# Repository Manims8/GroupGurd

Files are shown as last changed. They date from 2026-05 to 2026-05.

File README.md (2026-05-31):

# GroupGuard

GroupGuard is a wearable ESP32 safety and proximity system for groups moving through crowded places such as temples, festivals, tourist spots, campuses, and markets. The project helps prevent members, especially children and elderly people, from getting separated by giving real-time distance, direction, vibration alerts, LED alerts, and SOS signaling without requiring internet or a phone app.

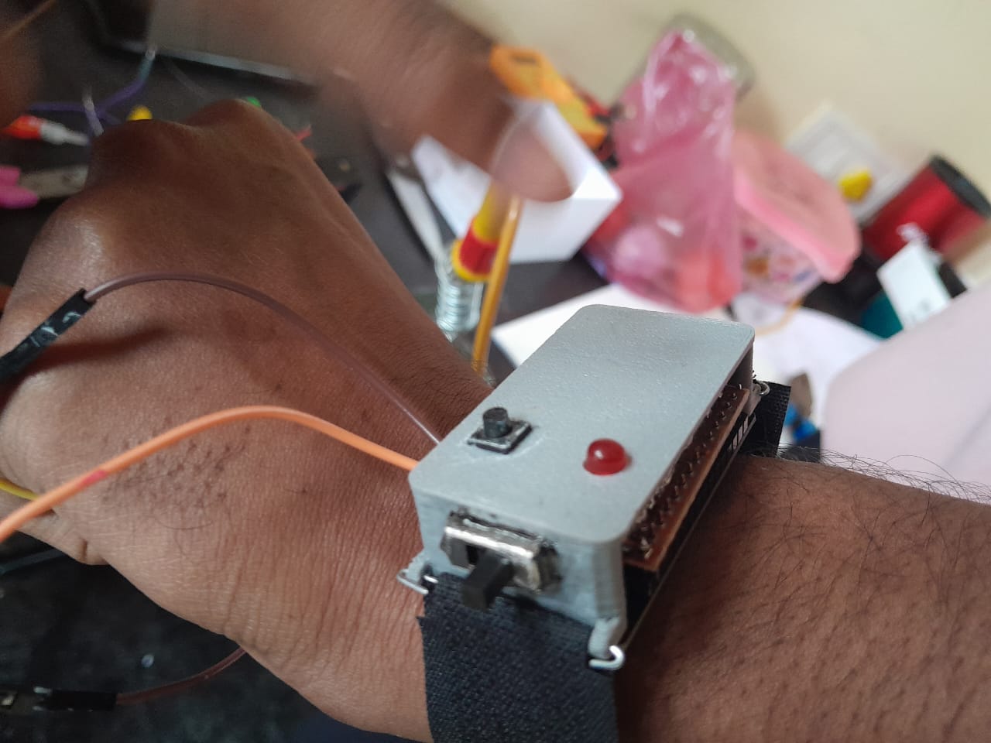
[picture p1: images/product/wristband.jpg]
GroupGuard wristband


## Problem

Crowded public spaces make it easy for group members to drift apart. Existing solutions such as CCTV, public announcements, or police assistance usually help only after someone is already missing. GroupGuard is designed as a proactive system: it alerts the group before separation becomes serious.

## Features

- Local WiFi network created by the master band, no router or internet required
- RSSI-based proximity estimation for group members
- QMC5883L compass-based directional guidance
- OLED direction and distance display on leader/display bands
- Vibration and LED alert patterns for warnings and SOS events
- Dedicated SOS button on each band
- 3D-printable enclosure models for display and non-display bands

## Demo Media

- Product photos: [`images/product/`](images/product/)
- Prototype photo: [`images/prototype/`](images/prototype/)
- Circuit diagram: [`images/circuit-diagrams/circuit diagram.png`](images/circuit-diagrams/circuit%20diagram.png)
- Demo videos: [`videos/`](videos/)
- 3D models: [`3D-designs/`](3D-designs/)

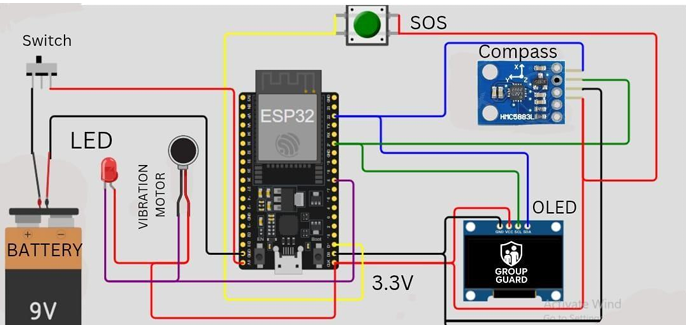
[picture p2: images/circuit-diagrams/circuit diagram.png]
Circuit diagram


## Firmware Layout

| Device | Sketch | Role |
| --- | --- | --- |
| D1 | `firmware/D1_Master/D1_Master.ino` | SoftAP, TCP server, warning sender, display master |
| D2 | `firmware/D2_Peripheral/D2_Peripheral.ino` | Headless peripheral with vibration and LED alerts |
| D3 | `firmware/D3_Display/D3_Display.ino` | Display peripheral showing D1 and D4 |
| D4 | `firmware/D4_Display/D4_Display.ino` | SPI display peripheral showing D3 and self |

## Documentation

- [Architecture](docs/architecture.md)
- [Problem Statement](docs/problem-statement.md)
- [Hardware](docs/hardware.md)
- [Communication Protocol](docs/protocol.md)
- [Testing](docs/testing.md)
- [Future Scope](docs/future-scope.md)

## Architecture

```mermaid
flowchart LR
  D1[D1 Master SoftAP<br/>192.168.4.1]
  D2[D2 Peripheral]
  D3[D3 Display]
  D4[D4 Display]

  D2 -->|D2,heading,sos,rssi| D1
  D3 -->|D3,heading,sos,rssi| D1
  D4 -->|D4,heading,sos,rssi| D1
  D1 -->|WARN| D2
  D1 -->|WARN + D1_DATA| D3
  D1 -->|WARN + D3_DATA| D4
```

## WiFi

D1 starts a SoftAP:

| Setting | Value |
| --- | --- |
| SSID | `GroupGuard` |
| Password | `Groupguard@0826` |
| D1 IP | `192.168.4.1` |
| D1 server port | `12345` |
| Peripheral server port | `54321` |

D1 does not show the WiFi password on the OLED during startup.

For public or shared deployments, change the default AP credentials in each firmware sketch before flashing.

## Hardware Pins

| Device | Button | Vibration | LED | I2C | Display |
| --- | --- | --- | --- | --- | --- |
| D1 | GPIO 15, pulldown, active-high | GPIO 5 | None | SDA 21, SCL 22 | I2C SSD1306 |
| D2 | GPIO 15, pulldown, active-high | GPIO 5 | GPIO 25 | SDA 21, SCL 22 | None |
| D3 | GPIO 15, pulldown, active-high | GPIO 5 | None | SDA 21, SCL 22 | I2C SSD1306 |
| D4 | GPIO 27, pullup, active-low | GPIO 26 | GPIO 25 | SDA 21, SCL 22 | SPI SSD1306, DC 5, RST 4 |

D4 intentionally keeps its existing active-low button wiring.

## Protocol

Peripheral uplink to D1:

```text
D#,<heading>,<sos>,<rssi>
```

D1 to D3:

```text
D1_DATA,<d1Heading>,<d3Distance>,<d4Heading>,<d4Distance>,<d4Sos>,<d4Active>
```

D1 to D4:

```text
D3_DATA,<d3Heading>,<d3Distance>,<d3Sos>,<d3Active>
```

Warning packet:

```text
WARN
```

## Flashing

Open each `.ino` in Arduino IDE from its matching folder, select the ESP32 board and port, install the required libraries, then upload:

- `WiFi`
- `Wire`
- `SPI`
- `QMC5883LCompass`
- `Adafruit GFX Library`
- `Adafruit SSD1306`

Flash D1 first so the `GroupGuard` access point is available, then flash D2, D3, and D4.

## Repository Contents

```text
firmware/      Arduino sketches for all four ESP32 devices
docs/          Architecture, hardware, protocol, testing, and future scope
images/        Product, prototype, and circuit images
videos/        Project demonstration videos
3D-designs/    STL enclosure models
```

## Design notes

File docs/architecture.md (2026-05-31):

# GroupGuard Architecture

## Device Responsibilities

D1 is the SoftAP and TCP master. It receives one-line CSV packets from D2, D3, and D4, computes approximate distance from RSSI, displays peer state, and sends warnings to every peripheral. It also relays D4 state to D3 and D3 state to D4.

D2 is headless and reports heading, SOS button state, and RSSI. It uses vibration and LED alerts.

D3 displays D1 and D4 in a two-column layout. D3 receives `D1_DATA` from D1 and reports its own state back to D1.

D4 displays D3 and self in the same two-column style. D4 receives `D3_DATA` from D1 and keeps its existing GPIO 27 active-low button wiring.

## Alert Patterns

| Event | Vibration | LED | Duration |
| --- | --- | --- | --- |
| SOS sent | 200 ms on / 200 ms off | Solid on where present | 2000 ms |
| Warning received | 300 ms on / 100 ms off | 150 ms flash where present | 3000 ms |
| D1 warning send | Solid vibration | None | 2000 ms |

## Display Model

Display devices use a split-screen peer box layout:

| Device | Left | Right |
| --- | --- | --- |
| D1 page 1 | D2 | D3 |
| D1 page 2 | D4 full-width | - |
| D3 | D1 | D4 |
| D4 | D3 | D4 self |

Each peer box shows a centered device label, a 32x30 direction arrow, and distance in meters.

## Distance Estimate

D1 estimates distance from RSSI:

```cpp
pow(10, (REF_RSSI - rssi) / (10.0 * PATH_LOSS))
```

This is an approximate proximity indicator and should be tuned in the real environment.

## Data Flow

1. Peripherals connect to D1's `GroupGuard` SoftAP.
2. Peripherals periodically send `D#,heading,sos,rssi` to D1 on port `12345`.
3. D1 updates the sender state using the sender IP from the TCP client.
4. D1 replies to D3 with D1 plus D4 state.
5. D1 replies to D4 with D3 state.
6. Pressing a warning/SOS button sends state through the same channel and triggers local alerts.

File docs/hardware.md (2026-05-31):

# Hardware

## Core Components

| Component | Purpose |
| --- | --- |
| ESP32-WROOM-32 | Main microcontroller, WiFi networking, GPIO control |
| QMC5883L/HMC5883L compass | Heading and direction sensing over I2C |
| 0.96 inch OLED display | Distance, direction, warning, and SOS display |
| Vibration motor | Haptic alert feedback |
| Push button | SOS or warning trigger |
| LED | Visual alert feedback where present |
| Li-ion/LiPo battery | Portable wearable power source |
| TP4056 charging module | Battery charging module |
| Wrist strap/enclosure | Wearable housing |

## Pin Mapping

| Device | Button | Vibration | LED | I2C | Display |
| --- | --- | --- | --- | --- | --- |
| D1 Master | GPIO 15, pulldown, active-high | GPIO 5 | None | SDA 21, SCL 22 | I2C SSD1306 |
| D2 Peripheral | GPIO 15, pulldown, active-high | GPIO 5 | GPIO 25 | SDA 21, SCL 22 | None |
| D3 Display | GPIO 15, pulldown, active-high | GPIO 5 | None | SDA 21, SCL 22 | I2C SSD1306 |
| D4 Display | GPIO 27, pullup, active-low | GPIO 26 | GPIO 25 | SDA 21, SCL 22 | SPI SSD1306, DC 5, RST 4 |

D4 intentionally uses an active-low button connected to ground. Do not change this wiring in firmware unless the physical circuit is changed.

## Circuit Diagram

Circuit diagram

## 3D Models

The repository includes two STL models:

- [`with_display.stl`](../3D-designs/with_display.stl)
- [`without_display.stl`](../3D-designs/without_display.stl)

These are intended for wristband enclosures with and without OLED display cutouts.

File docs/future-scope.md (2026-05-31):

# Future Scope

## PCB And Enclosure

Move from breadboard wiring to a custom PCB and compact enclosure. This will make the wristband smaller, more durable, and easier to wear.

## Power Optimization

Improve battery life by:

- Using ESP32 light sleep or modem sleep
- Reducing send frequency when members are close
- Increasing send frequency only when distance grows
- Turning off display or reducing refresh rate when idle

## Better Positioning

RSSI is useful for approximate threshold alerts, but not precise location. Future versions could explore:

- UWB for centimeter-level ranging
- BLE Mesh for larger low-power groups
- ESP-NOW for lightweight peer-to-peer ESP32 communication
- GPS for outdoor fallback tracking

## Mobile App

A companion app could help with:

- Naming devices
- Adjusting distance thresholds
- Viewing status of all bands
- Receiving phone notifications
- Saving test/calibration logs

## Scalability

The current system uses a star topology around D1. Larger groups may need a mesh or multi-leader architecture where family heads relay data to the main group leader.

## Field Testing

More testing should be done in:

- Busy markets
- Temples during rush hours
- Festivals
- Tourist locations
- Mixed indoor/outdoor routes

This would help tune RSSI thresholds and validate the system under realistic crowd movement.

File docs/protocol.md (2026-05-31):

# Communication Protocol

GroupGuard uses a local TCP network. D1 creates the WiFi access point and runs the central server on port `12345`. Peripherals run a server on port `54321` for warning and relay packets.

## Network

| Setting | Value |
| --- | --- |
| D1 SoftAP SSID | `GroupGuard` |
| D1 SoftAP IP | `192.168.4.1` |
| D1 server port | `12345` |
| Peripheral server port | `54321` |

Change the default password before using the project outside a controlled prototype environment.

## Peripheral To D1

Each peripheral periodically sends:

```text
D#,<heading>,<sos>,<rssi>
```

Example:

```text
D3,142,0,-61
```

Fields:

| Field | Meaning |
| --- | --- |
| `D#` | Device name, such as `D2`, `D3`, or `D4` |
| `heading` | Compass heading in degrees |
| `sos` | `1` if SOS is active, otherwise `0` |
| `rssi` | WiFi RSSI reading in dBm |

## D1 To D3

D1 sends D1 state plus D4 relay data to D3:

```text
D1_DATA,<d1Heading>,<d3Distance>,<d4Heading>,<d4Distance>,<d4Sos>,<d4Active>
```

## D1 To D4

D1 sends D3 relay data to D4:

```text
D3_DATA,<d3Heading>,<d3Distance>,<d3Sos>,<d3Active>
```

## Warning Packet

Warnings use a simple command:

```text
WARN
```

When received, peripherals trigger their vibration/LED warning pattern and display devices show a warning screen.

## Distance Formula

D1 estimates distance from RSSI:

```cpp
pow(10, (REF_RSSI - rssi) / (10.0 * PATH_LOSS))
```

RSSI distance is approximate and should be treated as a threshold signal, not exact measurement.

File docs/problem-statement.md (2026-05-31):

# Problem Statement

Group travel in crowded and dynamic environments creates a real risk of accidental separation. This is especially stressful when a group includes children, elderly people, or members who may not be able to communicate quickly in noisy public spaces.

Traditional solutions such as public announcements, CCTV monitoring, police assistance, or calling by phone are mostly reactive. They help after a person is already missing, which can cause panic, delay, and emotional distress.

GroupGuard addresses this by providing a proactive wearable system that continuously monitors group proximity and alerts members before separation becomes serious.

## Target Scenario

The system is intended for:

- Temples and pilgrimage areas
- Festivals and fairs
- Tourist destinations
- Crowded markets
- College or school trips
- Family group travel

## Objectives

- Monitor relative distance between group members in real time
- Provide vibration and LED alerts when a member moves beyond a safe threshold
- Show directional guidance on leader/display bands
- Allow any member to send an SOS alert
- Work without internet, phone apps, or external infrastructure
- Stay low-cost and simple enough for real-world wearable use

## Design Direction

The project uses ESP32 boards because they provide WiFi, TCP networking, GPIO control, and enough processing power at low cost. RSSI is used for approximate proximity detection, while QMC5883L compass readings provide direction cues. This combination is not meant for exact indoor positioning; it is meant to answer the practical safety question: "Who is too far, and which way should I look?"

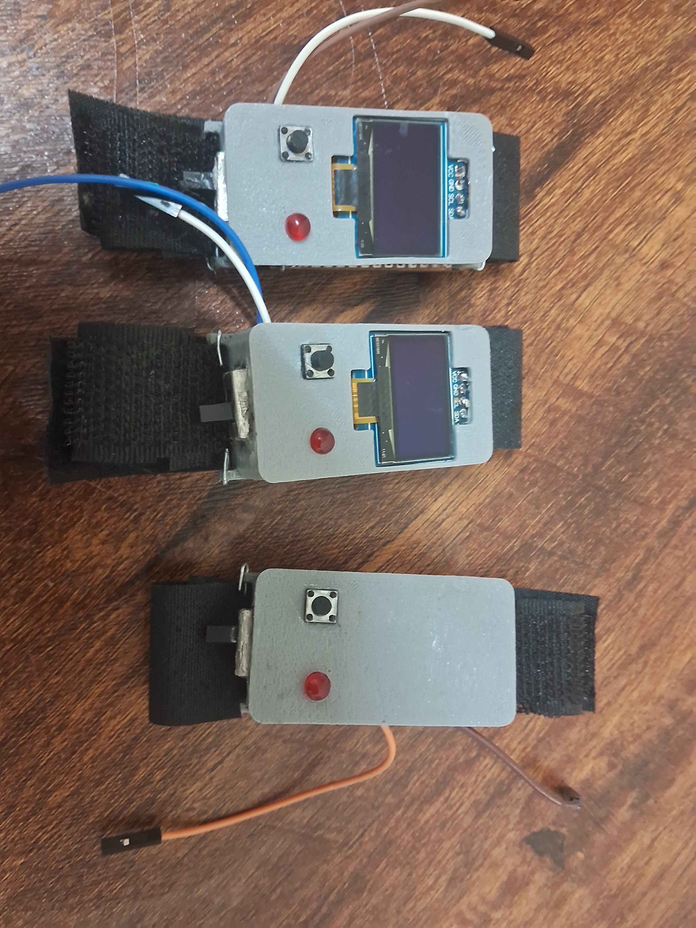
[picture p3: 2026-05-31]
images/product/products.jpg

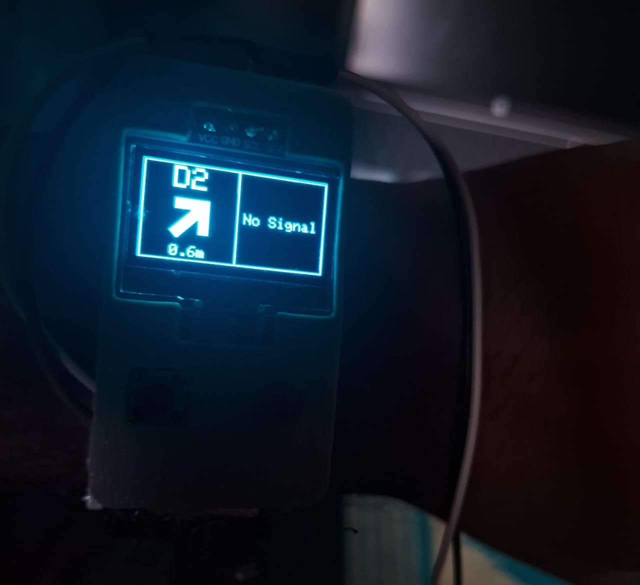
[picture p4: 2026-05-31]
images/product/D1.jpg

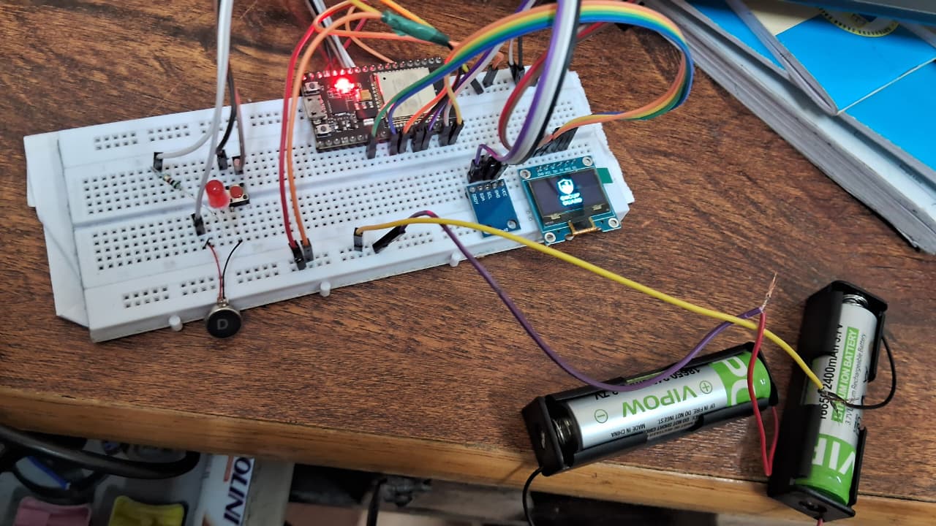
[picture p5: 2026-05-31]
images/prototype/img.jpeg

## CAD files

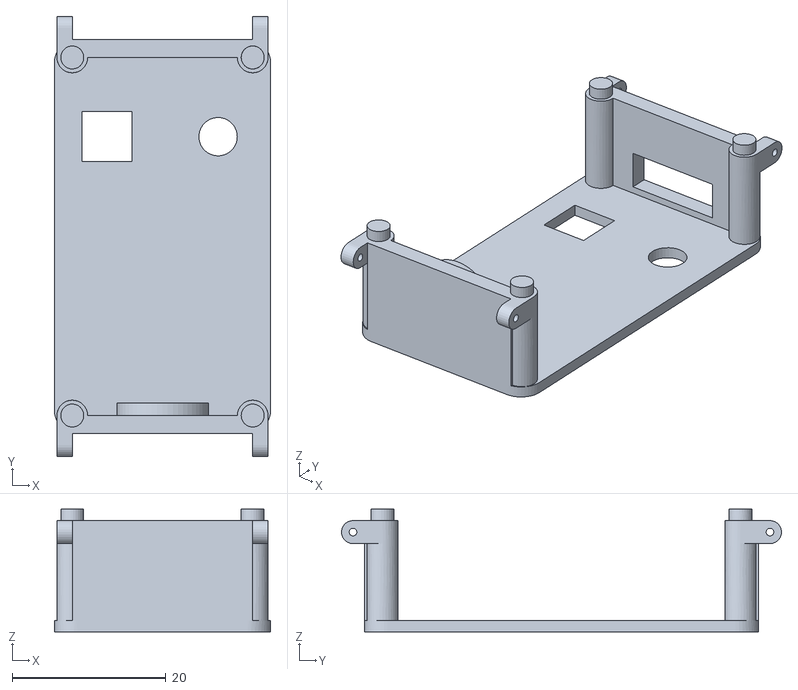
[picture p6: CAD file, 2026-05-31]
3D-designs/without_display.stl
28.2 x 57.3 x 16.0

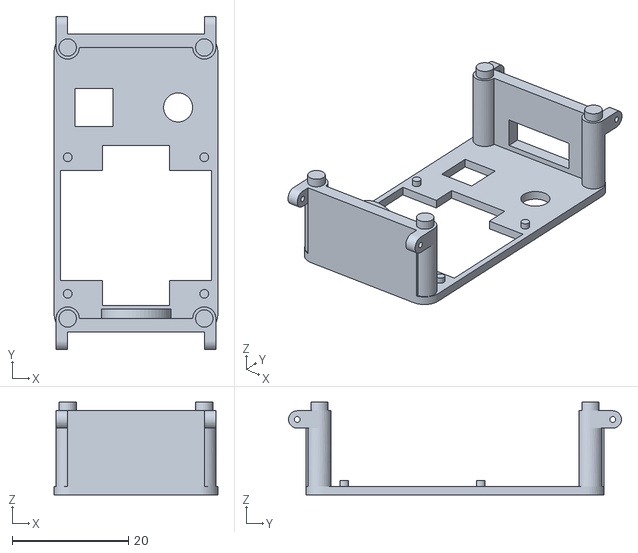
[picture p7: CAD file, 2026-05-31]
3D-designs/with_display.stl
28.2 x 57.3 x 16.0

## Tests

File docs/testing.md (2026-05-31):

# Testing

The prototype was tested in indoor and semi-open spaces to evaluate WiFi behavior, display updates, warning alerts, and SOS behavior.

## Test Locations

- College campus
- Hostel
- Residential home

These locations gave a mix of open paths, walls, people moving between devices, and different WiFi reflection/obstruction conditions.

## Tested Functions

| Function | Result |
| --- | --- |
| Real-time distance display | Worked with near-real-time updates |
| Direction arrow display | Worked after compass calibration |
| Threshold warnings | Triggered when devices crossed safe distance limits |
| SOS button | Displayed SOS state and triggered alerts |
| Local TCP communication | Responsive within the D1 access point network |
| Vibration and LED alerts | Worked as clear haptic/visual feedback |

## Observations

RSSI distance was useful for detecting whether a member is close enough or too far, but it was not stable enough for exact meter-by-meter measurement. Obstacles, people, walls, and device orientation caused fluctuation.

The compass made the system more practical because it gave the group leader a direction to check when a warning or SOS occurred. Compass calibration and avoiding magnetic interference are important for consistent direction display.

System latency was low enough for the prototype use case, with alerts appearing quickly after threshold crossing or SOS press.

## Limitations

- RSSI needs environment-specific calibration
- Crowds and obstacles can cause unstable distance values
- Continuous WiFi communication increases power usage
- Breadboard prototypes are not suitable for long-term wearable use
- More real-world festival/market testing is needed

## Outcome

The prototype validates the main idea: a low-cost wearable system can proactively warn a group before members become seriously separated.

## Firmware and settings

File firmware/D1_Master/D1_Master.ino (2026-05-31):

/*
 * =================================================================
 * D1 - MASTER DEVICE (CONTROLLER) - WI-FI VERSION (MODIFIED)
 * =================================================================
 *
 * Role:
 * 1. Hosts a TCP server to receive data from D2 & D3.
 * 2. Reads its own compass heading.
 * 3. Calculates distance via reported Wi-Fi RSSI from peripherals.
 * 4. Calculates and displays relative direction using bitmaps.
 * 5. Acts as a TCP client to send warnings to D2 & D3.
 * 6. Sends heading and distance data back to D3 for its display.
 *
 * HARDWARE: ESP32, QMC5883L, 0.96" OLED, Button, Vibration Motor
 *
 */

// LIBRARIES
#include <WiFi.h>
#include <Wire.h>
#include <QMC5883LCompass.h>
#include <Adafruit_GFX.h>
#include <Adafruit_SSD1306.h>
#include <cmath>

// =================== NETWORK CONFIGURATION ===================
const char* ssid = "GroupGuard";
const char* password = "Groupguard@0826";
IPAddress D2_IP;
IPAddress D3_IP;
IPAddress D4_IP;
const uint16_t D1_SERVER_PORT = 12345;
const uint16_t PERIPHERAL_PORT = 54321;
WiFiServer d1_server(D1_SERVER_PORT);

// =================== HARDWARE & DEVICE CONFIGURATION ===================
#define I2C_SDA 21
#define I2C_SCL 22
#define BUTTON_PIN 15
#define VIBRATION_MOTOR_PIN 5
#define SCREEN_WIDTH 128
#define SCREEN_HEIGHT 64
#define OLED_RESET -1
Adafruit_SSD1306 display(SCREEN_WIDTH, SCREEN_HEIGHT, &Wire, OLED_RESET);
QMC5883LCompass compass;

// =================== LOGO BITMAP ===================
const unsigned char logo_bitmap[] PROGMEM = {
	0x00, 0x00, 0x00, 0x00, 0x00, 0x00, 0x00, 0x00, 0x00, 0x00, 0x00, 0x00, 0x00, 0x00, 0x00, 0x00, 
	0x00, 0x00, 0x00, 0x00, 0x00, 0x00, 0x00, 0x00, 0x00, 0x00, 0x00, 0x00, 0x00, 0x00, 0x00, 0x00, 
	0x00, 0x00, 0x00, 0x00, 0x00, 0x00, 0x00, 0x00, 0x00, 0x00, 0x00, 0x00, 0x00, 0x00, 0x00, 0x00, 
	0x00, 0x00, 0x00, 0x00, 0x00, 0x00, 0x00, 0x00, 0x00, 0x00, 0x00, 0x00, 0x00, 0x00, 0x00, 0x00, 
	0x00, 0x00, 0x00, 0x00, 0x00, 0x00, 0x00, 0x00, 0x00, 0x00, 0x00, 0x00, 0x00, 0x00, 0x00, 0x00, 
	0x00, 0x00, 0x00, 0x00, 0x00, 0x00, 0x00, 0x01, 0x80, 0x00, 0x00, 0x00, 0x00, 0x00, 0x00, 0x00, 
	0x00, 0x00, 0x00, 0x00, 0x00, 0x00, 0x00, 0x07, 0xe0, 0x00, 0x00, 0x00, 0x00, 0x00, 0x00, 0x00, 
	0x00, 0x00, 0x00, 0x00, 0x00, 0x00, 0x00, 0x3e, 0x7c, 0x00, 0x00, 0x00, 0x00, 0x00, 0x00, 0x00, 
	0x00, 0x00, 0x00, 0x00, 0x00, 0x00, 0x01, 0xf8, 0x1f, 0x80, 0x00, 0x00, 0x00, 0x00, 0x00, 0x00, 
	0x00, 0x00, 0x00, 0x00, 0x00, 0x00, 0x1f, 0xc0, 0x03, 0xfc, 0x00, 0x00, 0x00, 0x00, 0x00, 0x00, 
	0x00, 0x00, 0x00, 0x00, 0x00, 0x00, 0x1c, 0x00, 0x00, 0x3c, 0x00, 0x00, 0x00, 0x00, 0x00, 0x00, 
	0x00, 0x00, 0x00, 0x00, 0x00, 0x00, 0x18, 0x00, 0x78, 0x0c, 0x00, 0x00, 0x00, 0x00, 0x00, 0x00, 
	0x00, 0x00, 0x00, 0x00, 0x00, 0x00, 0x18, 0x00, 0xfc, 0x0c, 0x00, 0x00, 0x00, 0x00, 0x00, 0x00, 
	0x00, 0x00, 0x00, 0x00, 0x00, 0x00, 0x18, 0x00, 0xfc, 0x0c, 0x00, 0x00, 0x00, 0x00, 0x00, 0x00, 
	0x00, 0x00, 0x00, 0x00, 0x00, 0x00, 0x18, 0x00, 0xfc, 0x0c, 0x00, 0x00, 0x00, 0x00, 0x00, 0x00, 
	0x00, 0x00, 0x00, 0x00, 0x00, 0x00, 0x18, 0x00, 0x7c, 0x0c, 0x00, 0x00, 0x00, 0x00, 0x00, 0x00, 
	0x00, 0x00, 0x00, 0x00, 0x00, 0x00, 0x18, 0x38, 0x38, 0x0c, 0x00, 0x00, 0x00, 0x00, 0x00, 0x00, 
	0x00, 0x00, 0x00, 0x00, 0x00, 0x00, 0x18, 0x7c, 0x00, 0x0c, 0x00, 0x00, 0x00, 0x00, 0x00, 0x00, 
	0x00, 0x00, 0x00, 0x00, 0x00, 0x00, 0x18, 0x7c, 0xfe, 0x0c, 0x00, 0x00, 0x00, 0x00, 0x00, 0x00, 
	0x00, 0x00, 0x00, 0x00, 0x00, 0x00, 0x18, 0x7d, 0xff, 0x0c, 0x00, 0x00, 0x00, 0x00, 0x00, 0x00, 
	0x00, 0x00, 0x00, 0x00, 0x00, 0x00, 0x18, 0x3b, 0xff, 0x8c, 0x00, 0x00, 0x00, 0x00, 0x00, 0x00, 
	0x00, 0x00, 0x00, 0x00, 0x00, 0x00, 0x18, 0x01, 0xff, 0x98, 0x00, 0x00, 0x00, 0x00, 0x00, 0x00, 
	0x00, 0x00, 0x00, 0x00, 0x00, 0x00, 0x18, 0x7c, 0xfd, 0x98, 0x00, 0x00, 0x00, 0x00, 0x00, 0x00, 
	0x00, 0x00, 0x00, 0x00, 0x00, 0x00, 0x18, 0xfe, 0xfd, 0x98, 0x00, 0x00, 0x00, 0x00, 0x00, 0x00, 
	0x00, 0x00, 0x00, 0x00, 0x00, 0x00, 0x19, 0xfe, 0xfd, 0x98, 0x00, 0x00, 0x00, 0x00, 0x00, 0x00, 
	0x00, 0x00, 0x00, 0x00, 0x00, 0x00, 0x0d, 0xfe, 0xfd, 0xb0, 0x00, 0x00, 0x00, 0x00, 0x00, 0x00, 
	0x00, 0x00, 0x00, 0x00, 0x00, 0x00, 0x0d, 0xfe, 0xfd, 0xb0, 0x00, 0x00, 0x00, 0x00, 0x00, 0x00, 
	0x00, 0x00, 0x00, 0x00, 0x00, 0x00, 0x07, 0xfa, 0xfd, 0xf0, 0x00, 0x00, 0x00, 0x00, 0x00, 0x00, 
	0x00, 0x00, 0x00, 0x00, 0x00, 0x00, 0x07, 0xfa, 0xfc, 0xe0, 0x00, 0x00, 0x00, 0x00, 0x00, 0x00, 
	0x00, 0x00, 0x00, 0x00, 0x00, 0x00, 0x03, 0xfa, 0xfc, 0xc0, 0x00, 0x00, 0x00, 0x00, 0x00, 0x00, 
	0x00, 0x00, 0x00, 0x00, 0x00, 0x00, 0x01, 0xfa, 0xff, 0x80, 0x00, 0x00, 0x00, 0x00, 0x00, 0x00, 
	0x00, 0x00, 0x00, 0x00, 0x00, 0x00, 0x00, 0xfa, 0xff, 0x00, 0x00, 0x00, 0x00, 0x00, 0x00, 0x00, 
	0x00, 0x00, 0x00, 0x00, 0x00, 0x00, 0x00, 0x78, 0xfe, 0x00, 0x00, 0x00, 0x00, 0x00, 0x00, 0x00, 
	0x00, 0x00, 0x00, 0x00, 0x00, 0x00, 0x00, 0x3c, 0xfc, 0x00, 0x00, 0x00, 0x00, 0x00, 0x00, 0x00, 
	0x00, 0x00, 0x00, 0x00, 0x00, 0x00, 0x00, 0x0f, 0xf0, 0x00, 0x00, 0x00, 0x00, 0x00, 0x00, 0x00, 
	0x00, 0x00, 0x00, 0x00, 0x00, 0x00, 0x00, 0x03, 0xc0, 0x00, 0x00, 0x00, 0x00, 0x00, 0x00, 0x00, 
	0x00, 0x00, 0x00, 0x00, 0x00, 0x00, 0x00, 0x00, 0x00, 0x00, 0x00, 0x00, 0x00, 0x00, 0x00, 0x00, 
	0x00, 0x00, 0x00, 0x00, 0x00, 0x00, 0x00, 0x00, 0x00, 0x00, 0x00, 0x00, 0x00, 0x00, 0x00, 0x00, 
	0x00, 0x00, 0x00, 0x00, 0x00, 0x01, 0x80, 0x01, 0x80, 0x00, 0x00, 0x00, 0x00, 0x00, 0x00, 0x00, 
	0x00, 0x00, 0x00, 0x00, 0x00, 0x07, 0xe7, 0xe7, 0xe2, 0x33, 0xe0, 0x00, 0x00, 0x00, 0x00, 0x00, 
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
};

// =================== NEW: 32x30 ARROW BITMAPS ===================
const unsigned char epd_bitmap_up[] PROGMEM = {
	0x00, 0x00, 0x00, 0x00, 0x00, 0x01, 0x80, 0x00, 0x00, 0x03, 0xc0, 0x00, 0x00, 0x07, 0xe0, 0x00, 
	0x00, 0x0f, 0xf0, 0x00, 0x00, 0x1f, 0xf8, 0x00, 0x00, 0x3f, 0xfc, 0x00, 0x00, 0x7f, 0xfe, 0x00, 
	0x00, 0xff, 0xff, 0x00, 0x01, 0xff, 0xff, 0x80, 0x03, 0xff, 0xff, 0xc0, 0x07, 0xff, 0xff, 0xe0, 
	0x0f, 0xff, 0xff, 0xf0, 0x1f, 0xff, 0xff, 0xf8, 0x3f, 0xff, 0xff, 0xfc, 0x00, 0x7f, 0xfe, 0x00, 
	0x00, 0x7f, 0xfe, 0x00, 0x00, 0x7f, 0xfe, 0x00, 0x00, 0x7f, 0xfe, 0x00, 0x00, 0x7f, 0xfe, 0x00, 
	0x00, 0x7f, 0xfe, 0x00, 0x00, 0x7f, 0xfe, 0x00, 0x00, 0x7f, 0xfe, 0x00, 0x00, 0x7f, 0xfe, 0x00, 
	0x00, 0x7f, 0xfe, 0x00, 0x00, 0x7f, 0xfe, 0x00, 0x00, 0x7f, 0xfe, 0x00, 0x00, 0x7f, 0xfe, 0x00, 
	0x00, 0x7f, 0xfe, 0x00, 0x00, 0x7f, 0xfe, 0x00
};

const unsigned char epd_bitmap_down[] PROGMEM = {
	0x00, 0x7f, 0xfe, 0x00, 0x00, 0x7f, 0xfe, 0x00, 0x00, 0x7f, 0xfe, 0x00, 0x00, 0x7f, 0xfe, 0x00, 
	0x00, 0x7f, 0xfe, 0x00, 0x00, 0x7f, 0xfe, 0x00, 0x00, 0x7f, 0xfe, 0x00, 0x00, 0x7f, 0xfe, 0x00, 
	0x00, 0x7f, 0xfe, 0x00, 0x00, 0x7f, 0xfe, 0x00, 0x00, 0x7f, 0xfe, 0x00, 0x00, 0x7f, 0xfe, 0x00, 
	0x00, 0x7f, 0xfe, 0x00, 0x00, 0x7f, 0xfe, 0x00, 0x00, 0x7f, 0xfe, 0x00, 0x3f, 0xff, 0xff, 0xfc, 
	0x1f, 0xff, 0xff, 0xf8, 0x0f, 0xff, 0xff, 0xf0, 0x07, 0xff, 0xff, 0xe0, 0x03, 0xff, 0xff, 0xc0, 
	0x01, 0xff, 0xff, 0x80, 0x00, 0xff, 0xff, 0x00, 0x00, 0x7f, 0xfe, 0x00, 0x00, 0x3f, 0xfc, 0x00, 
	0x00, 0x1f, 0xf8, 0x00, 0x00, 0x0f, 0xf0, 0x00, 0x00, 0x07, 0xe0, 0x00, 0x00, 0x03, 0xc0, 0x00, 
	0x00, 0x01, 0x80, 0x00, 0x00, 0x00, 0x00, 0x00
};

const unsigned char epd_bitmap_left[] PROGMEM = {
	0x00, 0x00, 0x00, 0x00, 0x00, 0x01, 0x00, 0x00, 0x00, 0x03, 0x00, 0x00, 0x00, 0x07, 0x00, 0x00, 
	0x00, 0x0f, 0x00, 0x00, 0x00, 0x1f, 0x00, 0x00, 0x00, 0x3f, 0x00, 0x00, 0x00, 0x7f, 0x00, 0x00, 
	0x00, 0xff, 0xff, 0xfe, 0x01, 0xff, 0xff, 0xfe, 0x03, 0xff, 0xff, 0xfe, 0x07, 0xff, 0xff, 0xfe, 
	0x0f, 0xff, 0xff, 0xfe, 0x1f, 0xff, 0xff, 0xfe, 0x3f, 0xff, 0xff, 0xfe, 0x3f, 0xff, 0xff, 0xfe, 
	0x1f, 0xff, 0xff, 0xfe, 0x0f, 0xff, 0xff, 0xfe, 0x07, 0xff, 0xff, 0xfe, 0x03, 0xff, 0xff, 0xfe, 
	0x01, 0xff, 0xff, 0xfe, 0x00, 0xff, 0xff, 0xfe, 0x00, 0x7f, 0x00, 0x00, 0x00, 0x3f, 0x00, 0x00, 
	0x00, 0x1f, 0x00, 0x00, 0x00, 0x0f, 0x00, 0x00, 0x00, 0x07, 0x00, 0x00, 0x00, 0x03, 0x00, 0x00, 
	0x00, 0x01, 0x00, 0x00, 0x00, 0x00, 0x00, 0x00
};

const unsigned char epd_bitmap_right[] PROGMEM = {
	0x00, 0x00, 0x00, 0x00, 0x00, 0x00, 0x80, 0x00, 0x00, 0x00, 0xc0, 0x00, 0x00, 0x00, 0xe0, 0x00, 
	0x00, 0x00, 0xf0, 0x00, 0x00, 0x00, 0xf8, 0x00, 0x00, 0x00, 0xfc, 0x00, 0x00, 0x00, 0xfe, 0x00, 
	0x7f, 0xff, 0xff, 0x00, 0x7f, 0xff, 0xff, 0x80, 0x7f, 0xff, 0xff, 0xc0, 0x7f, 0xff, 0xff, 0xe0, 
	0x7f, 0xff, 0xff, 0xf0, 0x7f, 0xff, 0xff, 0xf8, 0x7f, 0xff, 0xff, 0xfc, 0x7f, 0xff, 0xff, 0xfc, 
	0x7f, 0xff, 0xff, 0xf8, 0x7f, 0xff, 0xff, 0xf0, 0x7f, 0xff, 0xff, 0xe0, 0x7f, 0xff, 0xff, 0xc0, 
	0x7f, 0xff, 0xff, 0x80, 0x7f, 0xff, 0xff, 0x00, 0x00, 0x00, 0xfe, 0x00, 0x00, 0x00, 0xfc, 0x00, 
	0x00, 0x00, 0xf8, 0x00, 0x00, 0x00, 0xf0, 0x00, 0x00, 0x00, 0xe0, 0x00, 0x00, 0x00, 0xc0, 0x00, 
	0x00, 0x00, 0x80, 0x00, 0x00, 0x00, 0x00, 0x00
};

const unsigned char epd_bitmap_up_left[] PROGMEM = {
	0x7f, 0xff, 0xff, 0xf0, 0x7f, 0xff, 0xff, 0xf0, 0x7f, 0xff, 0xff, 0xf0, 0x7f, 0xff, 0xff, 0xf0, 
	0x7f, 0xff, 0xff, 0xf0, 0x7f, 0xff, 0xff, 0xf0, 0x7f, 0xff, 0xff, 0xf0, 0x7f, 0xff, 0xff, 0xf0, 
	0x7f, 0xfe, 0x00, 0x00, 0x7f, 0xff, 0x00, 0x00, 0x7f, 0xff, 0x80, 0x00, 0x7f, 0xff, 0xc0, 0x00, 
	0x7f, 0xff, 0xe0, 0x00, 0x7f, 0xff, 0xf0, 0x00, 0x7f, 0xbf, 0xf8, 0x00, 0x7f, 0x9f, 0xfc, 0x00, 
	0x7f, 0x8f, 0xfe, 0x00, 0x7f, 0x87, 0xff, 0x00, 0x7f, 0x83, 0xff, 0x80, 0x7f, 0x81, 0xff, 0xc0, 
	0x7f, 0x80, 0xff, 0xe0, 0x7f, 0x80, 0x7f, 0xf0, 0x7f, 0x80, 0x3f, 0xf8, 0x7f, 0x80, 0x1f, 0xfc, 
	0x7f, 0x80, 0x0f, 0xfe, 0x7f, 0x80, 0x07, 0xfc, 0x7f, 0x80, 0x03, 0xf8, 0x00, 0x00, 0x01, 0xf0, 
	0x00, 0x00, 0x00, 0xe0, 0x00, 0x00, 0x00, 0x40
};

const unsigned char epd_bitmap_up_right[] PROGMEM = {
	0x0f, 0xff, 0xff, 0xfe, 0x0f, 0xff, 0xff, 0xfe, 0x0f, 0xff, 0xff, 0xfe, 0x0f, 0xff, 0xff, 0xfe, 
	0x0f, 0xff, 0xff, 0xfe, 0x0f, 0xff, 0xff, 0xfe, 0x0f, 0xff, 0xff, 0xfe, 0x0f, 0xff, 0xff, 0xfe, 
	0x00, 0x00, 0x7f, 0xfe, 0x00, 0x00, 0xff, 0xfe, 0x00, 0x01, 0xff, 0xfe, 0x00, 0x03, 0xff, 0xfe, 
	0x00, 0x07, 0xff, 0xfe, 0x00, 0x0f, 0xff, 0xfe, 0x00, 0x1f, 0xfd, 0xfe, 0x00, 0x3f, 0xf9, 0xfe, 
	0x00, 0x7f, 0xf1, 0xfe, 0x00, 0xff, 0xe1, 0xfe, 0x01, 0xff, 0xc1, 0xfe, 0x03, 0xff, 0x81, 0xfe, 
	0x07, 0xff, 0x01, 0xfe, 0x0f, 0xfe, 0x01, 0xfe, 0x1f, 0xfc, 0x01, 0xfe, 0x3f, 0xf8, 0x01, 0xfe, 
	0x7f, 0xf0, 0x01, 0xfe, 0x3f, 0xe0, 0x01, 0xfe, 0x1f, 0xc0, 0x01, 0xfe, 0x0f, 0x80, 0x00, 0x00, 
	0x07, 0x00, 0x00, 0x00, 0x02, 0x00, 0x00, 0x00
};

const unsigned char epd_bitmap_down_left[] PROGMEM = {
	0x00, 0x00, 0x00, 0x40, 0x00, 0x00, 0x00, 0xe0, 0x00, 0x00, 0x01, 0xf0, 0x7f, 0x80, 0x03, 0xf8, 
	0x7f, 0x80, 0x07, 0xfc, 0x7f, 0x80, 0x0f, 0xfe, 0x7f, 0x80, 0x1f, 0xfc, 0x7f, 0x80, 0x3f, 0xf8, 
	0x7f, 0x80, 0x7f, 0xf0, 0x7f, 0x80, 0xff, 0xe0, 0x7f, 0x81, 0xff, 0xc0, 0x7f, 0x83, 0xff, 0x80, 
	0x7f, 0x87, 0xff, 0x00, 0x7f, 0x8f, 0xfe, 0x00, 0x7f, 0x9f, 0xfc, 0x00, 0x7f, 0xbf, 0xf8, 0x00, 
	0x7f, 0xff, 0xf0, 0x00, 0x7f, 0xff, 0xe0, 0x00, 0x7f, 0xff, 0xc0, 0x00, 0x7f, 0xff, 0x80, 0x00, 
	0x7f, 0xff, 0x00, 0x00, 0x7f, 0xfe, 0x00, 0x00, 0x7f, 0xff, 0xff, 0xf0, 0x7f, 0xff, 0xff, 0xf0, 
	0x7f, 0xff, 0xff, 0xf0, 0x7f, 0xff, 0xff, 0xf0, 0x7f, 0xff, 0xff, 0xf0, 0x7f, 0xff, 0xff, 0xf0, 
	0x7f, 0xff, 0xff, 0xf0, 0x7f, 0xff, 0xff, 0xf0
};

const unsigned char epd_bitmap_down_right[] PROGMEM = {
	0x02, 0x00, 0x00, 0x00, 0x07, 0x00, 0x00, 0x00, 0x0f, 0x80, 0x00, 0x00, 0x1f, 0xc0, 0x01, 0xfe, 
	0x3f, 0xe0, 0x01, 0xfe, 0x7f, 0xf0, 0x01, 0xfe, 0x3f, 0xf8, 0x01, 0xfe, 0x1f, 0xfc, 0x01, 0xfe, 
	0x0f, 0xfe, 0x01, 0xfe, 0x07, 0xff, 0x01, 0xfe, 0x03, 0xff, 0x81, 0xfe, 0x01, 0xff, 0xc1, 0xfe, 
	0x00, 0xff, 0xe1, 0xfe, 0x00, 0x7f, 0xf1, 0xfe, 0x00, 0x3f, 0xf9, 0xfe, 0x00, 0x1f, 0xfd, 0xfe, 
	0x00, 0x0f, 0xff, 0xfe, 0x00, 0x07, 0xff, 0xfe, 0x00, 0x03, 0xff, 0xfe, 0x00, 0x01, 0xff, 0xfe, 
	0x00, 0x00, 0xff, 0xfe, 0x00, 0x00, 0x7f, 0xfe, 0x0f, 0xff, 0xff, 0xfe, 0x0f, 0xff, 0xff, 0xfe, 
	0x0f, 0xff, 0xff, 0xfe, 0x0f, 0xff, 0xff, 0xfe, 0x0f, 0xff, 0xff, 0xfe, 0x0f, 0xff, 0xff, 0xfe, 
	0x0f, 0xff, 0xff, 0xfe, 0x0f, 0xff, 0xff, 0xfe
};

const unsigned char epd_bitmap_direction_none[] PROGMEM = {
	0x00, 0x00, 0x00, 0x00, 0x00, 0x1f, 0xf8, 0x00, 0x00, 0x3f, 0xfc, 0x00, 0x00, 0x7f, 0xfe, 0x00, 
	0x00, 0xff, 0xff, 0x00, 0x00, 0xfc, 0x3f, 0x00, 0x01, 0xf8, 0x1f, 0x00, 0x01, 0xf0, 0x1f, 0x80, 
	0x00, 0x00, 0x1f, 0x80, 0x00, 0x00, 0x1f, 0x00, 0x00, 0x00, 0x3f, 0x00, 0x00, 0x00, 0x7f, 0x00, 
	0x00, 0x01, 0xfe, 0x00, 0x00, 0x03, 0xfc, 0x00, 0x00, 0x03, 0xf0, 0x00, 0x00, 0x07, 0xe0, 0x00, 
	0x00, 0x07, 0xc0, 0x00, 0x00, 0x07, 0xc0, 0x00, 0x00, 0x07, 0xc0, 0x00, 0x00, 0x07, 0xc0, 0x00, 
	0x00, 0x07, 0xc0, 0x00, 0x00, 0x00, 0x00, 0x00, 0x00, 0x00, 0x00, 0x00, 0x00, 0x03, 0x00, 0x00, 
	0x00, 0x07, 0xc0, 0x00, 0x00, 0x0f, 0xc0, 0x00, 0x00, 0x0f, 0xc0, 0x00, 0x00, 0x0f, 0xc0, 0x00, 
	0x00, 0x07, 0x80, 0x00, 0x00, 0x00, 0x00, 0x00
};



// =================== DISTANCE & THRESHOLDS ===================
const float REF_RSSI = -45.0;
const float PATH_LOSS = 3.5;
const float D2_DISTANCE_THRESHOLD = 4.0;
const float D3_DISTANCE_THRESHOLD = 8.0;

// =================== GLOBAL VARIABLES & STATE ===================
struct DeviceState {
  String name;
  float distance = -1.0;
  int heading = -1;
  bool sos_active = false;
  unsigned long last_seen = 0;
  IPAddress ip;
};
DeviceState d2 = {"D2", -1.0, -1, false, 0};
DeviceState d3 = {"D3", -1.0, -1, false, 0};
DeviceState d4 = {"D4", -1.0, -1, false, 0};
int dir[10] = {0,0,0,0,0,0,0,0,0,0};
int hed ;
int myHeading = 0;
unsigned long lastDisplayUpdateTime = 0;
const unsigned long displayUpdateInterval = 100; // 10 FPS
bool sendingWarning = false;
bool lastButtonState = false;

// =================== UNIFIED ALERT STATE MACHINE ===================
bool alertActive = false;
unsigned long alertStartMillis = 0;
unsigned long alertDuration = 0;
unsigned long lastVibeToggle = 0;
int vibePulseOnTime = 0;
int vibePulseOffTime = 0;
bool vibePulseState = false;

// Display Page Toggling (for showing D2, D3, D4)
int displayPage = 0;
unsigned long lastPageChange = 0;

// =================== FUNCTION FORWARD DECLARATIONS ===================
void startSoftAP();
void handleIncomingData();
void sendWarning(IPAddress targetIP);
void sendDataToPeripheral(IPAddress targetIP, int heading, float distance);
void sendDataToD3(IPAddress targetIP, int heading, float distance, int d4Heading, float d4Distance, bool d4Sos, bool d4Active);
void sendDataToD4(IPAddress targetIP, int d3Heading, float d3Distance, bool d3Sos, bool d3Active);
void triggerAlert(unsigned long duration, int vibeOn, int vibeOff);
void handleAlerts();
int readCompassHeading();
void updateDisplay();
void drawSOSOverlay(const char* text);
void drawRangeWarning(const char* deviceName, float distance);
void drawPeerBox(int16_t x, int16_t y, int16_t w, int16_t h, const DeviceState &p);
const unsigned char* getArrowBitmap(float angle);
float normalizeAngle(float diff);
float calculateDistance(int rssi);

// =================== SETUP ===================
void setup() {
  Serial.begin(115200);
  Wire.begin(I2C_SDA, I2C_SCL);

  compass.init();
  pinMode(BUTTON_PIN, INPUT_PULLDOWN);
  pinMode(VIBRATION_MOTOR_PIN, OUTPUT);
  digitalWrite(VIBRATION_MOTOR_PIN, LOW);

  if (!display.begin(SSD1306_SWITCHCAPVCC, 0x3C)) {
    Serial.println(F("D1: SSD1306 allocation failed"));
    for (;;);
  }
  display.clearDisplay();
  display.drawBitmap(0, 0, logo_bitmap, 128, 64, SSD1306_WHITE);
  display.display();
  delay(2500); 

  D2_IP.fromString("192.168.86.139");
  D3_IP.fromString("192.168.86.224");
  D4_IP.fromString("192.168.86.225");
  d2.ip = D2_IP;
  d3.ip = D3_IP;
  d4.ip = D4_IP;

  startSoftAP();
  d1_server.begin();
}

// =================== MAIN LOOP ===================
void loop() {
  handleIncomingData();
  myHeading = readCompassHeading();
  handleAlerts();

  bool buttonPressed = (digitalRead(BUTTON_PIN) == HIGH);
  if (buttonPressed && !lastButtonState) {
    Serial.println("[D1] Button pressed. Sending warning...");
    sendingWarning = true;
    triggerAlert(2000, 2000, 0);

    sendWarning(D2_IP);
    sendWarning(D3_IP);
    sendWarning(D4_IP);
  }
  lastButtonState = buttonPressed;

  if (millis() - lastDisplayUpdateTime > displayUpdateInterval) {
    updateDisplay();
    lastDisplayUpdateTime = millis();
  }
}

// =================== NETWORK FUNCTIONS ===================
void startSoftAP() {
  display.clearDisplay();
  display.setTextColor(SSD1306_WHITE);
  display.setTextSize(1);
  display.setCursor(0, 0);
  display.println("D1 MASTER (SoftAP)");
  display.println("Starting SoftAP...");
  display.display();
  Serial.println("Starting SoftAP...");

  // Start ESP32 in Access Point mode
  WiFi.softAP(ssid, password);

  IPAddress myIP = WiFi.softAPIP();
  Serial.print("AP IP address: ");
  Serial.println(myIP);

  display.clearDisplay();
  display.setCursor(0, 0);
  display.println("D1 MASTER");
  display.println("Initializing...");
  display.println("IP Address:");
  display.println(myIP);
  display.display();
  delay(1500);
}

void handleIncomingData() {
  WiFiClient client = d1_server.available();
  if (client) {
    IPAddress remoteIP = client.remoteIP(); // Capture remote IP address before client.stop()
    String data = client.readStringUntil('\n');
    client.stop();
    data.trim();
    Serial.print("[D1] Received data: ");
    Serial.println(data);

    char data_cstr[64];
    data.toCharArray(data_cstr, 64);
    char* token = strtok(data_cstr, ",");

    if (token != NULL) {
      String name = token;
      DeviceState* current_device = nullptr;
      if (name == "D2") current_device = &d2;
      else if (name == "D3") current_device = &d3;
      else if (name == "D4") current_device = &d4;

      if (current_device) {
        current_device->ip = remoteIP; // Dynamically update IP address of the peer!
        bool previousSos = current_device->sos_active;
        token = strtok(NULL, ","); if (token) current_device->heading = atoi(token);
        token = strtok(NULL, ","); if (token) current_device->sos_active = (bool)atoi(token);
        token = strtok(NULL, ","); if (token) current_device->distance = calculateDistance(atoi(token));
        current_device->last_seen = millis();

        if (!previousSos && current_device->sos_active) {
            triggerAlert(3000, 300, 100);
        }

        if (name == "D3") {
            bool d4Active = (millis() - d4.last_seen < 5000);
            sendDataToD3(current_device->ip, myHeading, current_device->distance, d4.heading, d4.distance, d4.sos_active, d4Active);
        } else if (name == "D4") {
            bool d3Active = (millis() - d3.last_seen < 5000);
            sendDataToD4(current_device->ip, d3.heading, d3.distance, d3.sos_active, d3Active);
        }
      }
    }
  }
}

void sendWarning(IPAddress targetIP) {
  WiFiClient client;
  if (!client.connect(targetIP, PERIPHERAL_PORT)) {
    Serial.print("[D1] Warning connection to "); Serial.print(targetIP); Serial.println(" failed!");
    return;
  }
  client.println("WARN");
  client.stop();
  Serial.print("[D1] Warning sent to "); Serial.println(targetIP);
}

void sendDataToPeripheral(IPAddress targetIP, int heading, float distance) {
    WiFiClient client;
    if (!client.connect(targetIP, PERIPHERAL_PORT)) {
        Serial.print("[D1] Data connection to "); Serial.print(targetIP); Serial.println(" failed!");
        return;
    }
    char dataPacket[64];
    snprintf(dataPacket, sizeof(dataPacket), "D1_DATA,%d,%.2f", heading, distance);
    client.println(dataPacket);
    client.stop();
    Serial.print("[D1] Sent data packet to "); Serial.println(targetIP);
}

void sendDataToD3(IPAddress targetIP, int heading, float distance, int d4Heading, float d4Distance, bool d4Sos, bool d4Active) {
    WiFiClient client;
    if (!client.connect(targetIP, PERIPHERAL_PORT)) {
        Serial.print("[D1] Data connection to D3 failed!");
        return;
    }
    char dataPacket[64];
    snprintf(dataPacket, sizeof(dataPacket), "D1_DATA,%d,%.2f,%d,%.2f,%d,%d",
             heading, distance, d4Heading, d4Distance, d4Sos ? 1 : 0, d4Active ? 1 : 0);
    client.println(dataPacket);
    client.stop();
    Serial.print("[D1] Sent data packet to D3: "); Serial.println(dataPacket);
}

void sendDataToD4(IPAddress targetIP, int d3Heading, float d3Distance, bool d3Sos, bool d3Active) {
    WiFiClient client;
    if (!client.connect(targetIP, PERIPHERAL_PORT)) {
        Serial.print("[D1] Data connection to D4 failed!");
        return;
    }
    char dataPacket[64];
    snprintf(dataPacket, sizeof(dataPacket), "D3_DATA,%d,%.2f,%d,%d",
             d3Heading, d3Distance, d3Sos ? 1 : 0, d3Active ? 1 : 0);
    client.println(dataPacket);
    client.stop();
    Serial.print("[D1] Sent data packet to D4: "); Serial.println(dataPacket);
}

// =================== DISPLAY & HELPER FUNCTIONS ===================
void triggerAlert(unsigned long duration, int vibeOn, int vibeOff) {
    alertActive = true;
    alertStartMillis = millis();
    alertDuration = duration;
    vibePulseOnTime = vibeOn;
    vibePulseOffTime = vibeOff;
    vibePulseState = (vibeOn > 0);
    digitalWrite(VIBRATION_MOTOR_PIN, vibePulseState ? HIGH : LOW);
    lastVibeToggle = millis();
}

void handleAlerts() {
    if (!alertActive) {
        digitalWrite(VIBRATION_MOTOR_PIN, LOW);
        sendingWarning = false;
        return;
    }

    if (millis() - alertStartMillis > alertDuration) {
        alertActive = false;
        digitalWrite(VIBRATION_MOTOR_PIN, LOW);
        sendingWarning = false;
        return;
    }

    if (vibePulseOnTime > 0 && vibePulseOffTime > 0) {
        unsigned long interval = vibePulseState ? vibePulseOnTime : vibePulseOffTime;
        if (millis() - lastVibeToggle >= interval) {
            vibePulseState = !vibePulseState;
            digitalWrite(VIBRATION_MOTOR_PIN, vibePulseState ? HIGH : LOW);
            lastVibeToggle = millis();
        }
    } else {
        digitalWrite(VIBRATION_MOTOR_PIN, vibePulseOnTime > 0 ? HIGH : LOW);
    }
}

int readCompassHeading() {
  hed = 0;
  compass.read();
  for (int i = 0; i <= 9; ++i) {
    dir[i] = compass.getAzimuth();
    hed += dir[i];
  }
  return hed / 10;
}
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

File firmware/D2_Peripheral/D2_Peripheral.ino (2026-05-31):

/*
 * =================================================================
 * D2 - PERIPHERAL DEVICE (NO DISPLAY) - WI-FI VERSION (UNIFIED)
 * =================================================================
 *
 * Role:
 * 1. Acts as a TCP client to send data to D1.
 * 2. Hosts a TCP server to listen for warnings from D1.
 * 3. Reads compass and sends heading, SOS status, and Wi-Fi RSSI.
 * 4. Activates vibration motor and LED on warning or SOS trigger.
 *
 * HARDWARE: ESP32, QMC5883L, Button, Vibration Motor, LED
 *
 */

// LIBRARIES
#include <WiFi.h>
#include <Wire.h>
#include <QMC5883LCompass.h>

// =================== NETWORK CONFIGURATION ===================
const char* ssid = "GroupGuard";
const char* password = "Groupguard@0826";
IPAddress D1_SERVER_IP;
const uint16_t D1_SERVER_PORT = 12345;
const uint16_t MY_SERVER_PORT = 54321;
WiFiServer my_server(MY_SERVER_PORT);

// =================== HARDWARE & DEVICE CONFIGURATION ===================
#define I2C_SDA 21
#define I2C_SCL 22
#define BUTTON_PIN 15
#define VIBRATION_MOTOR_PIN 5
#define LED_PIN 25 // Optional LED (Active-High)
#define DEVICE_NAME "D2"

QMC5883LCompass compass;

// =================== GLOBAL VARIABLES & STATE ===================
int dir[10] = {0,0,0,0,0,0,0,0,0,0};
int hed;
int myHeading = 0;
bool sosActive = false;
volatile bool warningReceived = false;

unsigned long lastSendTime = 0;
const unsigned long sendInterval = 1000;

// =================== UNIFIED ALERT STATE MACHINE ===================
bool alert_active = false;
unsigned long alert_start_millis = 0;
unsigned long alert_duration = 0;
unsigned long last_vibe_toggle = 0;
unsigned long last_led_toggle = 0;
int vibe_pulse_on_time = 0;
int vibe_pulse_off_time = 0;
int led_pulse_on_time = 0;
int led_pulse_off_time = 0;
bool vibe_pulse_state = false;
bool led_pulse_state = false;

void triggerAlert(unsigned long duration, int vibeOn, int vibeOff, int ledOn, int ledOff) {
    alert_active = true;
    alert_start_millis = millis();
    alert_duration = duration;
    vibe_pulse_on_time = vibeOn;
    vibe_pulse_off_time = vibeOff;
    led_pulse_on_time = ledOn;
    led_pulse_off_time = ledOff;
    
    // Initial vibration state
    if (vibeOn > 0) {
        vibe_pulse_state = true;
        digitalWrite(VIBRATION_MOTOR_PIN, HIGH);
    } else {
        vibe_pulse_state = false;
        digitalWrite(VIBRATION_MOTOR_PIN, LOW);
    }
    
    // Initial LED state
    if (ledOn > 0) {
        led_pulse_state = true;
        digitalWrite(LED_PIN, HIGH);
    } else {
        led_pulse_state = false;
        digitalWrite(LED_PIN, LOW);
    }
    
    last_vibe_toggle = millis();
    last_led_toggle = millis();
}

void handleAlerts() {
    if (!alert_active) {
        digitalWrite(VIBRATION_MOTOR_PIN, LOW);
        digitalWrite(LED_PIN, LOW);
        return;
    }
    
    // Check if alert duration has expired
    if (millis() - alert_start_millis > alert_duration) {
        alert_active = false;
        digitalWrite(VIBRATION_MOTOR_PIN, LOW);
        digitalWrite(LED_PIN, LOW);
        return;
    }
    
    // Handle non-blocking vibration pulsing
    if (vibe_pulse_on_time > 0 && vibe_pulse_off_time > 0) {
        unsigned long current_vibe_interval = vibe_pulse_state ? vibe_pulse_on_time : vibe_pulse_off_time;
        if (millis() - last_vibe_toggle >= current_vibe_interval) {
            vibe_pulse_state = !vibe_pulse_state;
            digitalWrite(VIBRATION_MOTOR_PIN, vibe_pulse_state ? HIGH : LOW);
            last_vibe_toggle = millis();
        }
    } else if (vibe_pulse_on_time == 0) {
        digitalWrite(VIBRATION_MOTOR_PIN, LOW);
    } else {
        digitalWrite(VIBRATION_MOTOR_PIN, HIGH);
    }
    
    // Handle non-blocking LED pulsing
    if (led_pulse_on_time > 0 && led_pulse_off_time > 0) {
        unsigned long current_led_interval = led_pulse_state ? led_pulse_on_time : led_pulse_off_time;
        if (millis() - last_led_toggle >= current_led_interval) {
            led_pulse_state = !led_pulse_state;
            digitalWrite(LED_PIN, led_pulse_state ? HIGH : LOW);
            last_led_toggle = millis();
        }
    } else if (led_pulse_on_time == 0) {
        digitalWrite(LED_PIN, LOW);
    } else {
        digitalWrite(LED_PIN, HIGH);
    }
}

// =================== FUNCTION PROTOTYPES ===================
void connectToWiFi();
void handleIncomingWarnings();
void sendDataToMaster();
int readCompassHeading();

// =================== SETUP ===================
void setup() {
  Serial.begin(115200);
  Wire.begin(I2C_SDA, I2C_SCL);

  // Init hardware
  compass.init();
  pinMode(BUTTON_PIN, INPUT_PULLDOWN);
  pinMode(VIBRATION_MOTOR_PIN, OUTPUT);
  pinMode(LED_PIN, OUTPUT);
  digitalWrite(VIBRATION_MOTOR_PIN, LOW);
  digitalWrite(LED_PIN, LOW);

  // Set D1's IP to SoftAP address
  D1_SERVER_IP.fromString("192.168.4.1");

  // Connect to Wi-Fi and start server
  connectToWiFi();
  my_server.begin();
  Serial.println("D2: Ready");
}

// =================== MAIN LOOP ===================
void loop() {
  // 1. Check for incoming warnings from D1
  handleIncomingWarnings();

  // 2. Handle warning received (Pulses 300ms ON / 100ms OFF for 3s, LED solid)
  if (warningReceived) {
    Serial.println("[D2] Warning received!");
    triggerAlert(3000, 300, 100, 150, 150); 
    warningReceived = false; 
  }
  
  // 3. Process non-blocking alerts
  handleAlerts();

  // 4. Periodically send data to D1
  if (millis() - lastSendTime > sendInterval) {
    // Check SOS button status
    sosActive = (digitalRead(BUTTON_PIN) == HIGH);
    if (sosActive) {
      Serial.println("[D2] SOS ACTIVE!");
      triggerAlert(2000, 200, 200, 2000, 0); 
    }

    myHeading = readCompassHeading();

    // Send data packet
    sendDataToMaster();
    lastSendTime = millis();
  }
}

// =================== NETWORK FUNCTIONS ===================
void connectToWiFi() {
  Serial.print("Connecting to "); Serial.println(ssid);
  WiFi.begin(ssid, password);
  while (WiFi.status() != WL_CONNECTED) {
    delay(500);
    Serial.print(".");
  }
  Serial.println("\nWiFi Connected.");
  Serial.print("D2 IP address: "); Serial.println(WiFi.localIP());
}

void handleIncomingWarnings() {
  WiFiClient client = my_server.available();
  if (client) {
    String command = client.readStringUntil('\n');
    client.stop();
    command.trim();
    if (command == "WARN") {
      warningReceived = true;
    }
  }
}

void sendDataToMaster() {
  WiFiClient client;
  if (!client.connect(D1_SERVER_IP, D1_SERVER_PORT)) {
    Serial.println("Connection to D1 master failed!");
    return;
  }

  // Create data packet: "NAME,HEADING,SOS,RSSI"
  long rssi = WiFi.RSSI();
  char dataPacket[64];
  snprintf(dataPacket, sizeof(dataPacket), "%s,%d,%d,%ld", DEVICE_NAME, myHeading, sosActive ? 1 : 0, rssi);

  client.println(dataPacket);
  client.stop();
  Serial.print("Sent data: "); Serial.println(dataPacket);
}
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
